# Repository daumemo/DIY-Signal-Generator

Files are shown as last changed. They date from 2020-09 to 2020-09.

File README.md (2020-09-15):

# DIY-Signal-Generator

diy-generator-image

A device, used for generating electrical signals. More infromation: https://daumemo.com/finished-diy-portable-wi-fi-function-generator-part-17

Repository includes all files: firmware code, schematics, PCB files.
STL files for the enclosure can be found here: https://www.thingiverse.com/thing:4596954

Device's specification:
- 3.5 inch IPS LCD with capacitive touch panel
- 2200 mAh Li-Po battery
- ESP-32 MCU
- AD9833 for sine and triangle waveform generation (up to 25 MHz)
- Square wave and PWM generated by the MCU (up to 5 MHz)
- The device can be controlled through LCD or WEB interface
- For WEB control, the device can connect to a Wi-Fi or it can create its own Wi-Fi Access Point
- Output signal’s offset range: -8V … +8V
- Output signal’s amplitude range: 0 … 9V (sine, triangle), 0 … 5.5V (square). PWM output: 3V.
- Battery charging time: <2 hours
- Working time (Wi-Fi on, output relay ON, maximum LCD brightness): around 6 hours
- USB Type C port for charging, 2 SMA ports for signal output, 1 ON/OFF switch, LED charging indicator

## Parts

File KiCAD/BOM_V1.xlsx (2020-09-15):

Date: | 2020-05-26 00:24 | additional modification 2020-09-15
Tool: | Eeschema (5.1.4)-1
NOTE: capacitor voltages specified below are recommended values - it is OK to use capacitors with greater rated voltage. To use lower value - you will need to inspect schematic and decide if lower voltage is acceptable
Component Count: | 141
Ref | Value | Footprint | Description | Remarks, links etc.
C1 | 1u 10V | SMD 0603 | Unpolarized capacitor
C2 | 1u 10V | SMD 0603 | Unpolarized capacitor
C3 | 470n 16V | SMD 0603 | Unpolarized capacitor
C4 | 470n 16V | SMD 0603 | Unpolarized capacitor
C5 | 10uF 6V | SMD 0603 | Unpolarized capacitor
C6 | 10n 50V | SMD 0603 | Unpolarized capacitor
C7 | 22u 6V | SMD 0603 | Unpolarized capacitor
C8 | 100n 50V | SMD 0603 | Unpolarized capacitor
C9 | 470n 16V | SMD 0603 | Unpolarized capacitor
C10 | 2u2 10V | SMD 0603 | Unpolarized capacitor
C11 | 470n 16V | SMD 0603 | Unpolarized capacitor
C12 | 2u2 10V | SMD 0603 | Unpolarized capacitor
C13 | 100n 50V | SMD 0603 | Unpolarized capacitor
C14 | not soldered in | SMD 0603 | Unpolarized capacitor (not soldered in)
C15 | 100n 50V | SMD 0603 | Unpolarized capacitor
C16 | 1u 16V | SMD 0603 | Unpolarized capacitor
C17 | 100n 50V | SMD 0603 | Unpolarized capacitor
C18 | 1u 16V | SMD 0603 | Unpolarized capacitor
C19 | 100u 6V | SMD Case-B (EIA-3528) | Polarized tantalum capacitor
C20 | 100n 50V | SMD 0603 | Unpolarized capacitor
C21 | 4u7 6V | SMD 0603 | Unpolarized capacitor
C22 | 1u 10V | SMD 0603 | Unpolarized capacitor
C23 | 10n 50V | SMD 0603 | Unpolarized capacitor
C24 | 220n 16V | SMD 0603 | Unpolarized capacitor
C25 | 4n7 50V | SMD 0603 | Unpolarized capacitor
C26 | 47n 16V | SMD 0603 | Unpolarized capacitor
C27 | 4u7 6V | SMD 0603 | Unpolarized capacitor
C28 | 4u7 16V | SMD 0805 | Unpolarized capacitor
C29 | 10u 6V | SMD 0603 | Unpolarized capacitor
C30 | 10u 6V | SMD 0603 | Unpolarized capacitor
C31 | 4u7 16V | SMD 0805 | Unpolarized capacitor
C32 | 22u 16V | SMD Case-B (EIA-3528) | Polarized tantalum capacitor
C33 | 22u 16V | SMD Case-B (EIA-3528) | Polarized tantalum capacitor
C34 | 10u 6V | SMD 0603 | Unpolarized capacitor
C35 | 10u 10V | SMD 0603 | Unpolarized capacitor
C36 | 220uf 6V | SMD Case-C (EIA-6032) | Polarized tantalum capacitor
C37 | 100n 50V | SMD 0603 | Unpolarized capacitor
C38 | 12p 50V | SMD 0603 | Unpolarized capacitor
C39 | 2u2 6V | SMD 0603 | Unpolarized capacitor
C40 | 10u 6V | SMD 0603 | Unpolarized capacitor
C41 | 100u 6V | SMD Case-B (EIA-3528) | Polarized tantalum capacitor
C42 | 12p 50V | SMD 0603 | Unpolarized capacitor
C43 | 470n 16V | SMD 0603 | Unpolarized capacitor
C44 | 10u 6V | SMD 0603 | Unpolarized capacitor
C45 | 10u 10V | SMD 0603 | Unpolarized capacitor
C46 | 100u 6V | SMD 1206 | Unpolarized capacitor
C47 | 10n 50V | SMD 0603 | Unpolarized capacitor
C48 | 10u 6V | SMD 0603 | Unpolarized capacitor
C49 | 1u 10V | SMD 0603 | Unpolarized capacitor
C50 | 10u 6V | SMD 0603 | Unpolarized capacitor
C51 | 5n6 25V | SMD 0603 | Unpolarized capacitor
C52 | 5n6 25V | SMD 0603 | Unpolarized capacitor
D1 | LED, amber | SMD LED 0603 | Light emitting diode
D2 | PMEG3010EH | SMD SOD-123 | Schottky diode | Could be used similar diode
D3 | PMEG3010EH | SMD SOD-123 | Schottky diode | Could be used similar diode
D4 | PMEG3010EH | SMD SOD-123 | Diode | Can be a regular diode in SOD-123 case
J1 | Wave_Out | SMA-J-P-X-ST-EM1_EdgeMount | coaxial connector SMA | https://www.aliexpress.com/item/32948380887.html?spm=a2g0s.9042311.0.0.27424c4doeMCJ3
J2 | PWM_Out | SMA-J-P-X-ST-EM1_EdgeMount | coaxial connector SMA | https://www.aliexpress.com/item/32948380887.html?spm=a2g0s.9042311.0.0.27424c4doeMCJ3
J3 | USB_C_Receptacle_USB2.0 | Type-C:HRO-TYPE-C-31-M-12-HandSoldering | USB 2.0-only Type-C Receptacle connector | https://www.aliexpress.com/item/32962977859.html?spm=a2g0s.9042311.0.0.27424c4depynTn
J4 | TS |  | PCB connector
J5 | GND |  | PCB connector
J6 | BAT |  | PCB connector | Lipo/Liion Battery +
J7 | GND |  | PCB connector | Lipo/Liion Battery -
J8 | UART |  | PCB connector
J9 | I2C (not soldered in) | FinalPCB:User_FPC_4pin_05pitch_bot_cont | FPC 4pin connector | Not soldered in (not used)
J10 | 40pin_LCD | FinalPCB:User_FPC_40pin_05pitch_BottomContact | FPC 40pin horizontal bottom contact connector
J11 | LCD_Touch | FinalPCB:User_FPC_6pin_05pitch_top_cont | FPC 6pin horizontal top contact connector
K1 | G6K-2F-Y | Relay_DPDT_Omron_G6K-2F-Y | Miniature 2-pole relay, Single-side Stable
L1 | 4u7 | SMD:4x4mm NRS4012T4R7MDGJ | Inductor | https://eu.mouser.com/ProductDetail/Taiyo-Yuden/NRS4012T4R7MDGJ?qs=PzICbMaShUcMjc7xtptbAQ%3D%3D
L2 | 4u7 | SMD:4x4mm NRS4012T4R7MDGJ | Inductor | https://eu.mouser.com/ProductDetail/Taiyo-Yuden/NRS4012T4R7MDGJ?qs=PzICbMaShUcMjc7xtptbAQ%3D%3D
L3 | 2u2 | SMD:4x4mm NRS4012T2R2MDGJ | Inductor | https://eu.mouser.com/ProductDetail/Taiyo-Yuden/NRS4012T2R2MDGJ
L4 | 4u7 | SMD:4x4mm NRS4012T4R7MDGJ | Inductor | https://eu.mouser.com/ProductDetail/Taiyo-Yuden/NRS4012T4R7MDGJ?qs=PzICbMaShUcMjc7xtptbAQ%3D%3D
L5 | 4u7 | SMD:4x4mm NRS4012T4R7MDGJ | Inductor | https://eu.mouser.com/ProductDetail/Taiyo-Yuden/NRS4012T4R7MDGJ?qs=PzICbMaShUcMjc7xtptbAQ%3D%3D
Q1 | BC847C | SMD SOT-23 | 0.1A Ic, 45V Vce, NPN Transistor, SOT-23
Q2 | NTR4003NT1G | SMD SOT-23 | N-MOSFET transistor, gate/source/drain
Q3 | NTR4003NT1G | SMD SOT-23 | N-MOSFET transistor, gate/source/drain
R1 | 1k3 | SMD 0603 | Resistor
R2 | 3k9 | SMD 0603 | Resistor
R3 | 22k | SMD 0603 | Resistor
R4 | 22k | SMD 0603 | Resistor
R5 | 2k | SMD 0603 | Resistor
R6 | 2k | SMD 0603 | Resistor
R7 | 9k1 | SMD 0603 | Resistor
R8 | 1k | SMD 0603 | Resistor
R9 | 1k3 | SMD 0603 | Resistor
R10 | 3k9 | SMD 0603 | Resistor
R11 | 200 | SMD 0603 | Resistor
R12 | 1k | SMD 0603 | Resistor
R13 | 22k | SMD 0603 | Resistor
R14 | 22k | SMD 0603 | Resistor
R15 | 1k | SMD 0603 | Resistor
R16 | 0 | SMD 0603 | Resistor
R17 | not soldered in | SMD 0603 | Resistor
R18 | 240 | SMD 0603 | Resistor
R19 | 240 | SMD 0603 | Resistor
R20 | 240 | SMD 0603 | Resistor
R21 | 910 | SMD 0603 | Resistor
R22 | 18k | SMD 0603 | Resistor
R23 | 0 | SMD 0805 | Resistor
R24 | 100 | SMD 0603 | Resistor
R25 | 5k1 | SMD 0603 | Resistor
R26 | 5k1 | SMD 0603 | Resistor
R27 | 10k | SMD 0603 | Resistor
R28 | 10k | SMD 0603 | Resistor
R29 | 0 | SMD 0603 | Resistor
R30 | 0 or not soldered | SMD 0603 | Resistor | if soldered in - power saving mode
R31 | 0 | SMD 0603 | Resistor
R32 | 0 or not soldered | SMD 0603 | Resistor | if soldered in - power saving mode
R33 | 240 | SMD 0603 | Resistor
R34 | 10k | SMD 0603 | Resistor
R35 | 1k8 | SMD 0603 | Resistor
R36 | 100k | SMD 0603 | Resistor
R37 | 1M | SMD 0603 | Resistor
R38 | 4k3 | SMD 0603 | Resistor
R39 | 20k | SMD 0603 | Resistor
R40 | 1M | SMD 0603 | Resistor
R41 | 110k | SMD 0603 | Resistor
R42 | 15k | SMD 0603 | Resistor
R43 | 20k | SMD 0603 | Resistor
R44 | 160k | SMD 0603 | Resistor
R45 | 51k | SMD 0603 | Resistor
R46 | 100 | SMD 0603 | Resistor
R47 | 130k | SMD 0603 | Resistor
R48 | 56k | SMD 0603 | Resistor
R49 | 12k | SMD 0603 | Resistor
R50 | 10k | SMD 0603 | Resistor
R51 | 3k3 | SMD 0603 | Resistor
R52 | 3k3 | SMD 0603 | Resistor
R53 | 1M | SMD 0603 | Resistor
R54 | 0 | SMD 0603 | Resistor
R55 | 0 | SMD 0603 | Resistor
R56 | 1R | SMD 1206 | Resistor
R57 | 470 | SMD 0603 | Resistor
SW1 |  | FinalPCB:Switch | Single Pole Single Throw (SPST) switch | https://www.aliexpress.com/item/32852841524.html?scm_id=1007.14977.165002.0&scm-url=1007.14977.165002.0
U1 | OPA2196 | SOIC:SOIC-8_3.9x4.9mm_Pitch1.27mm | Dual SoundPlus High Performance Audio Operational Amplifiers SOIC-8
U2 | VCA822 | SSOP:MSOP-10_3x3mm_Pitch0.5mm | Variable gain operational amplifier
U3 | LM7171 | SOIC:SOIC-8_3.9x4.9mm_Pitch1.27mm | High bandwidth operational amplifier
U4 | TPS65131 | QFN-24-1EP_4x4mm_Pitch0.5mm | DC-DC converter
U5 | BQ24295 | QFN-24-1EP_4x4mm_Pitch0.5mm | Battery charging IC
U6 | LDL1117-3.0 | SOT-223-3_TabPin2 | 1A Fixed LDO Linear Regulator, 3.0V SOT-223
U7 | LV52117QA | LV52117:LV52117QA | DC-DC converter
U8 | ESP32-WROOM-32 | ESP32-WROOM-32 | RF Module, ESP32-D0WDQ6 SoC, Wi-Fi 802.11b/g/n, Bluetooth, BLE, 32-bit, 2.7-3.6V, onboard antenna, SMD | https://www.aliexpress.com/item/32799985552.html?spm=a2g0s.9042311.0.0.27424c4doeMCJ3
U9 | AD9833_module | AD9833_module |  | https://www.aliexpress.com/item/32998169276.html
EXTERNAL COMPONENTS:
LCD 3.5 inch |  | Connected to J11 and J10 |  | https://www.aliexpress.com/item/32940608152.html
Thermistor | NTCLG100E2103JB | Connected to J4 and J5 | Could be used similar | https://eu.mouser.com/ProductDetail/Vishay-BC-Components/NTCLG100E2103JB
Battery |  |  | Li-Po 2200mAh 405580 | https://www.aliexpress.com/item/32986724542.html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

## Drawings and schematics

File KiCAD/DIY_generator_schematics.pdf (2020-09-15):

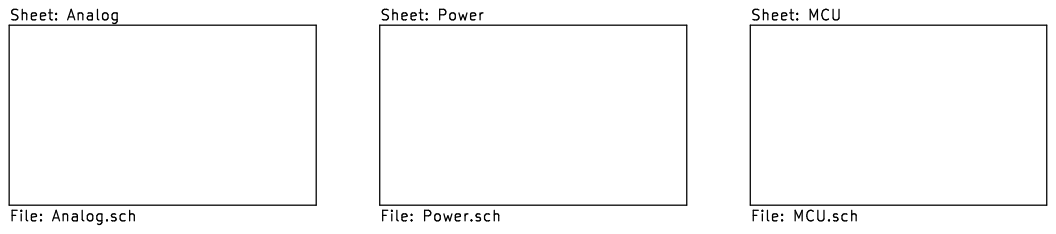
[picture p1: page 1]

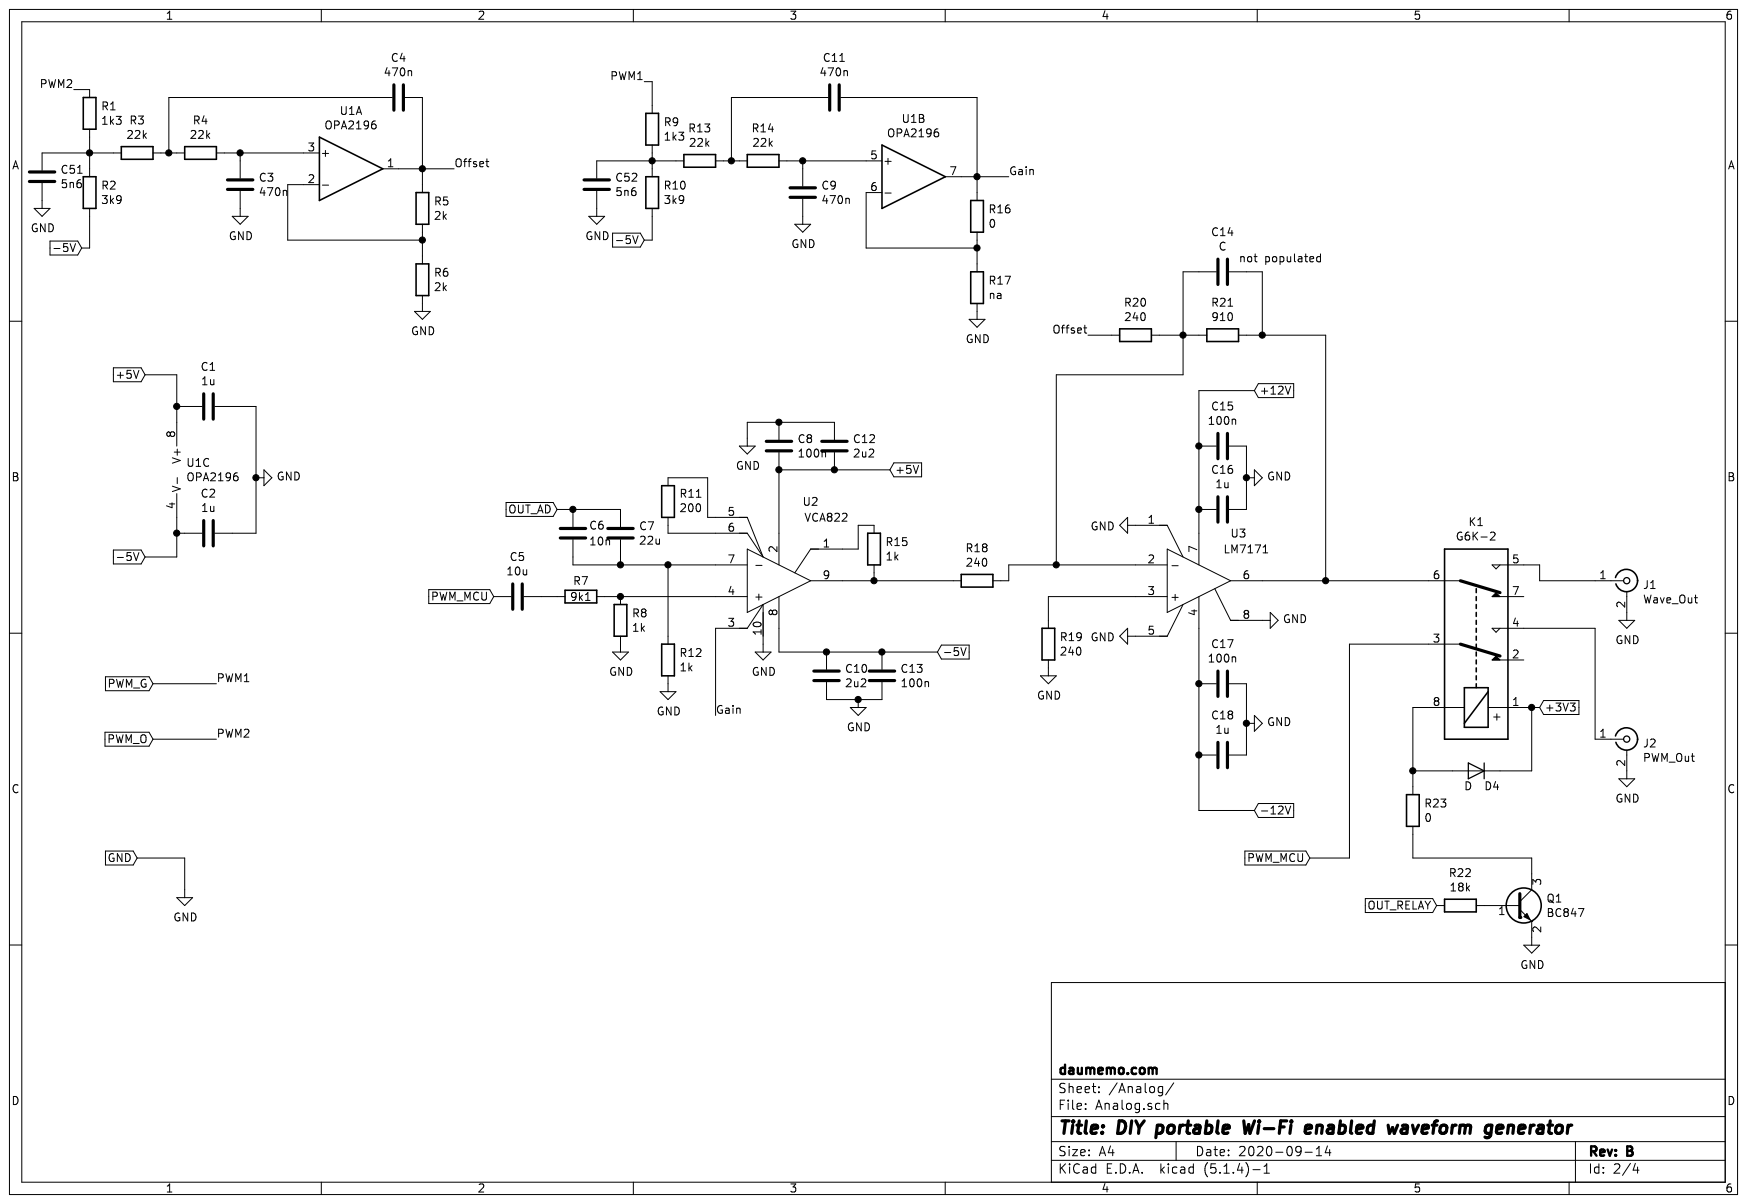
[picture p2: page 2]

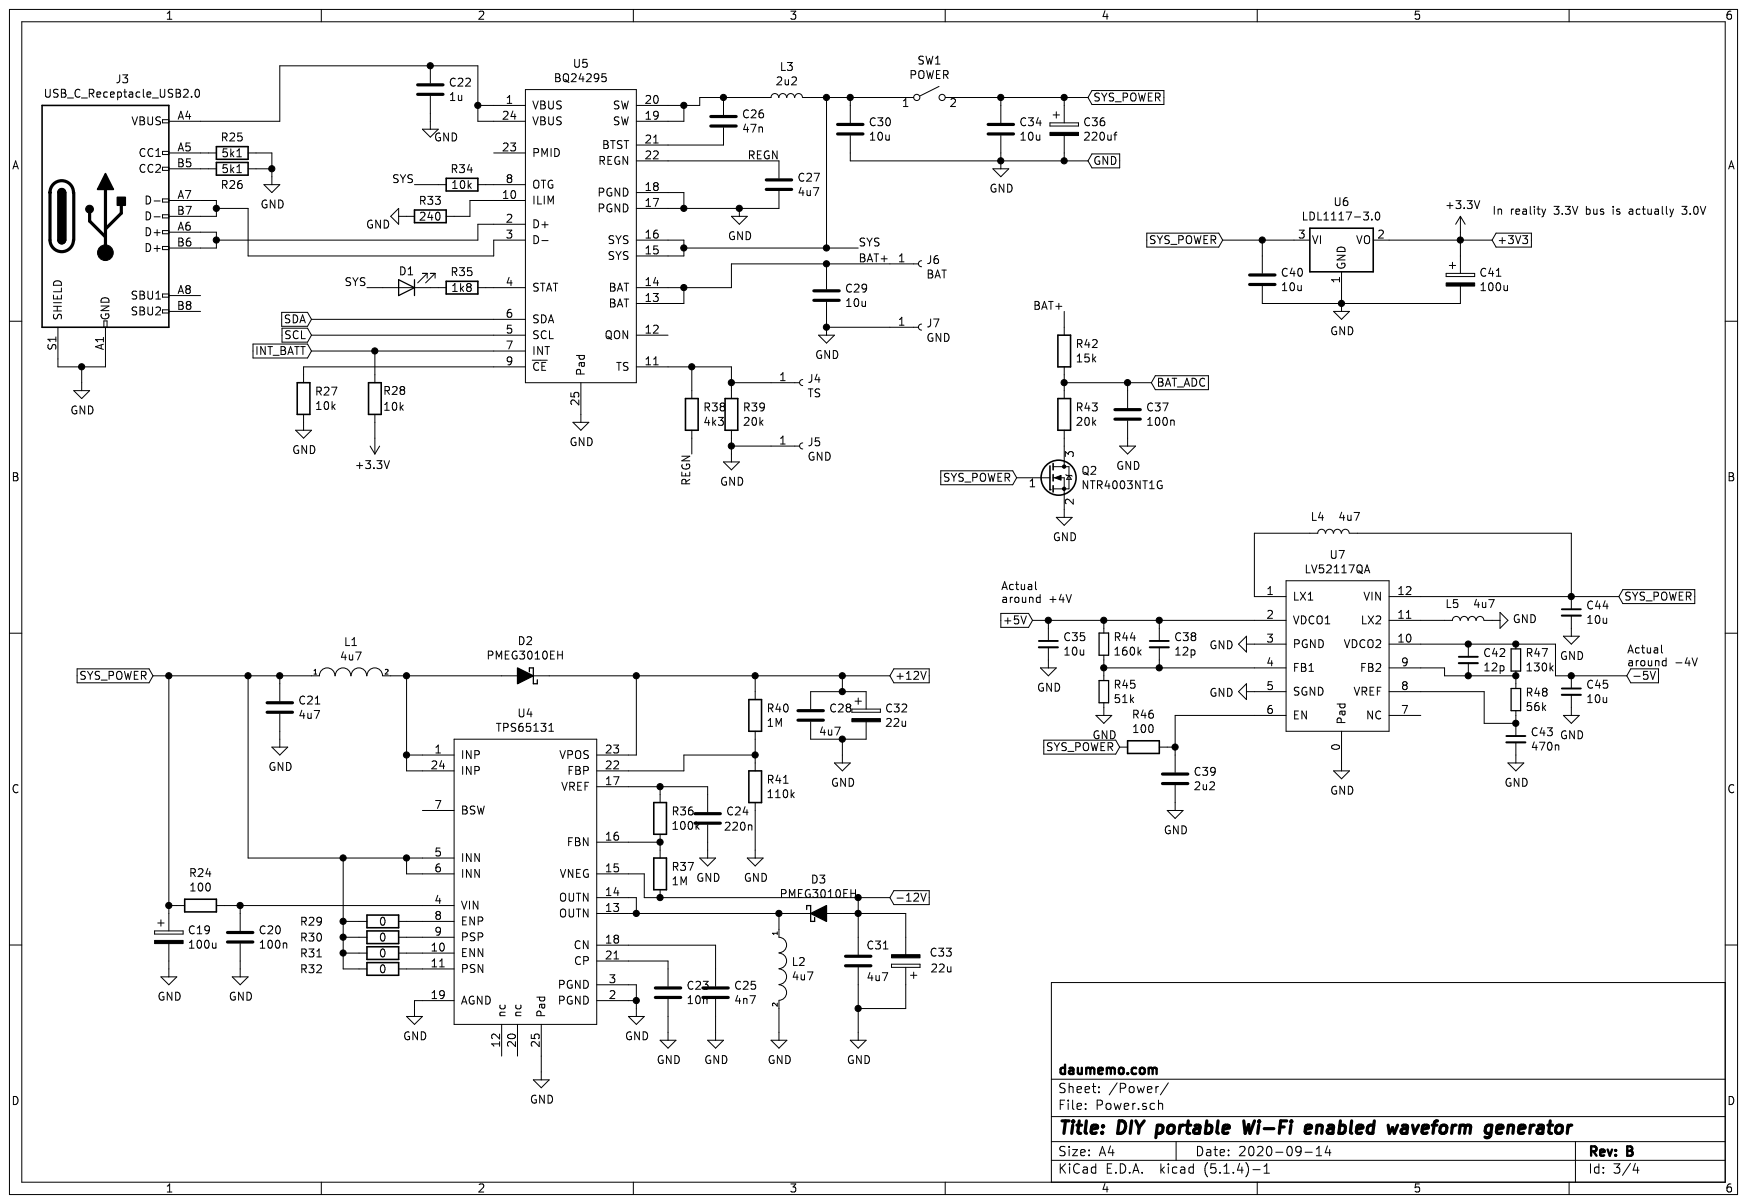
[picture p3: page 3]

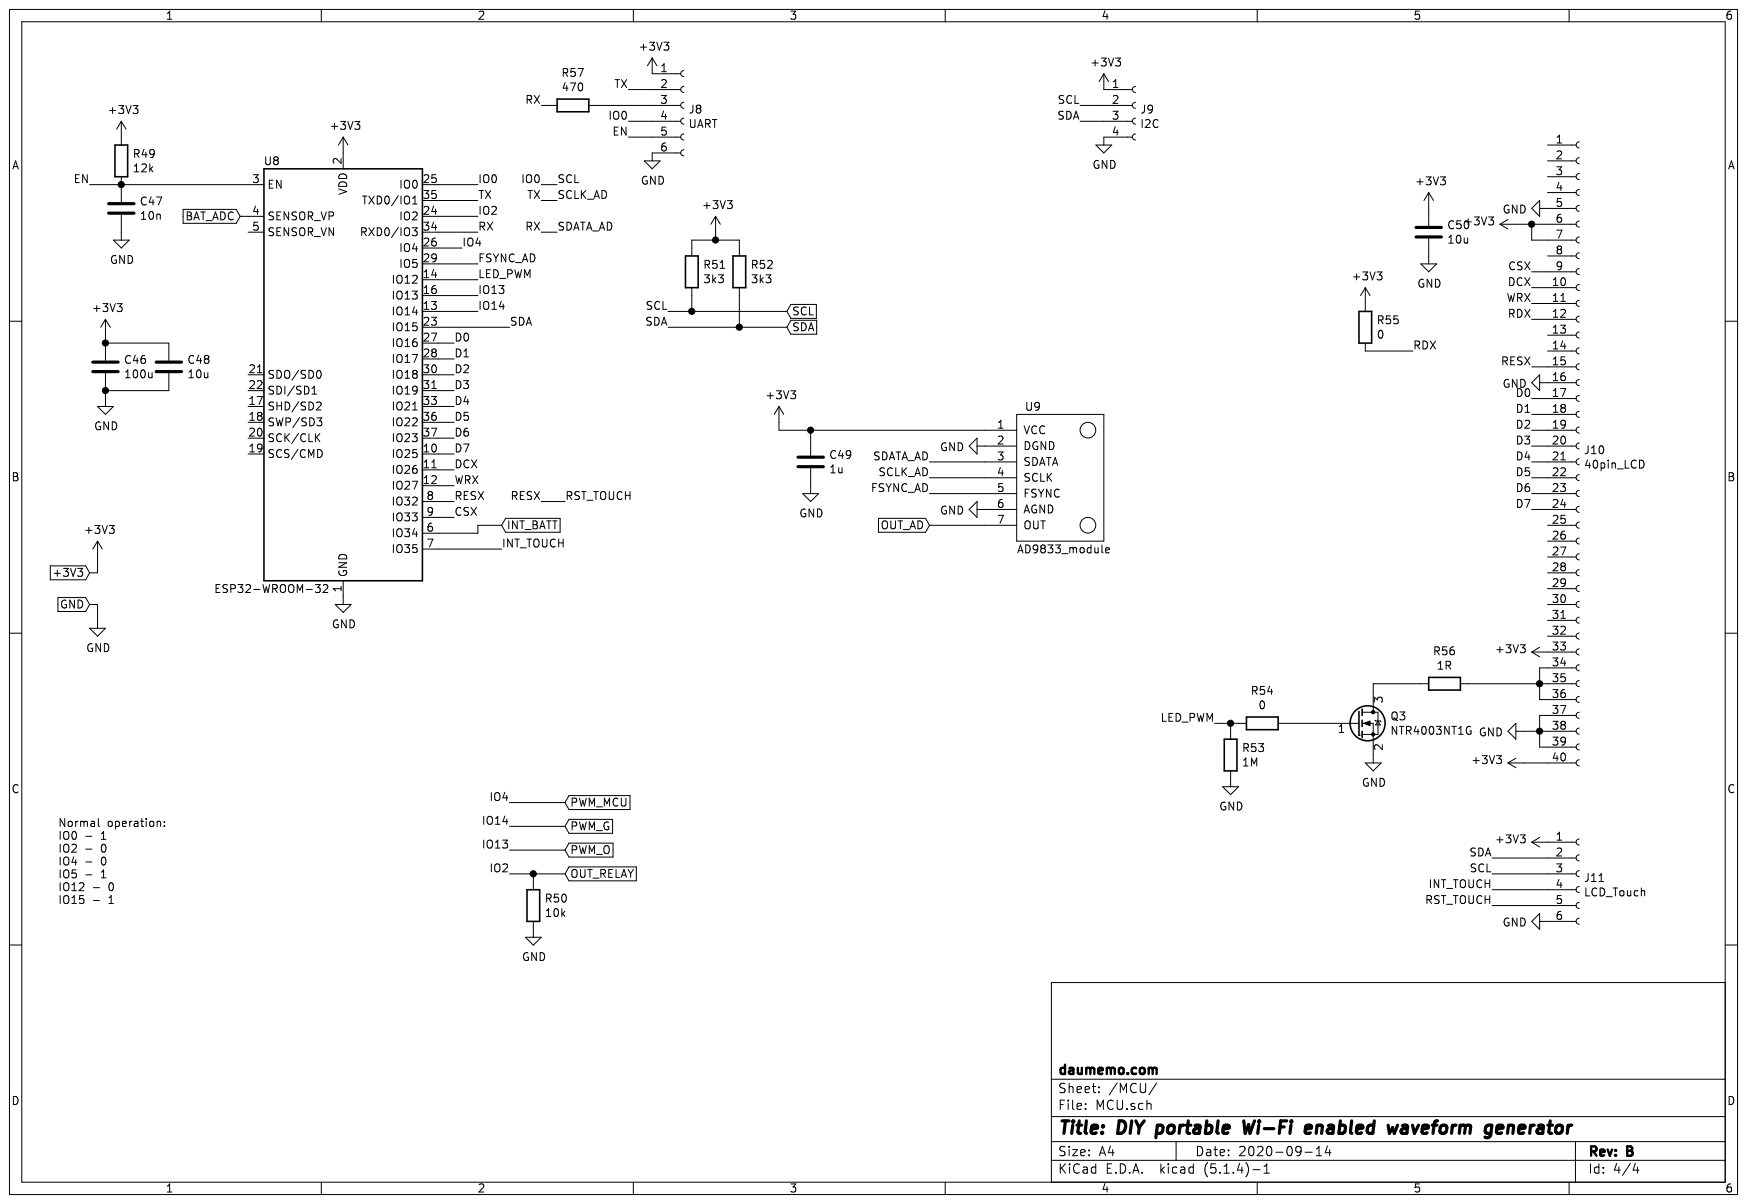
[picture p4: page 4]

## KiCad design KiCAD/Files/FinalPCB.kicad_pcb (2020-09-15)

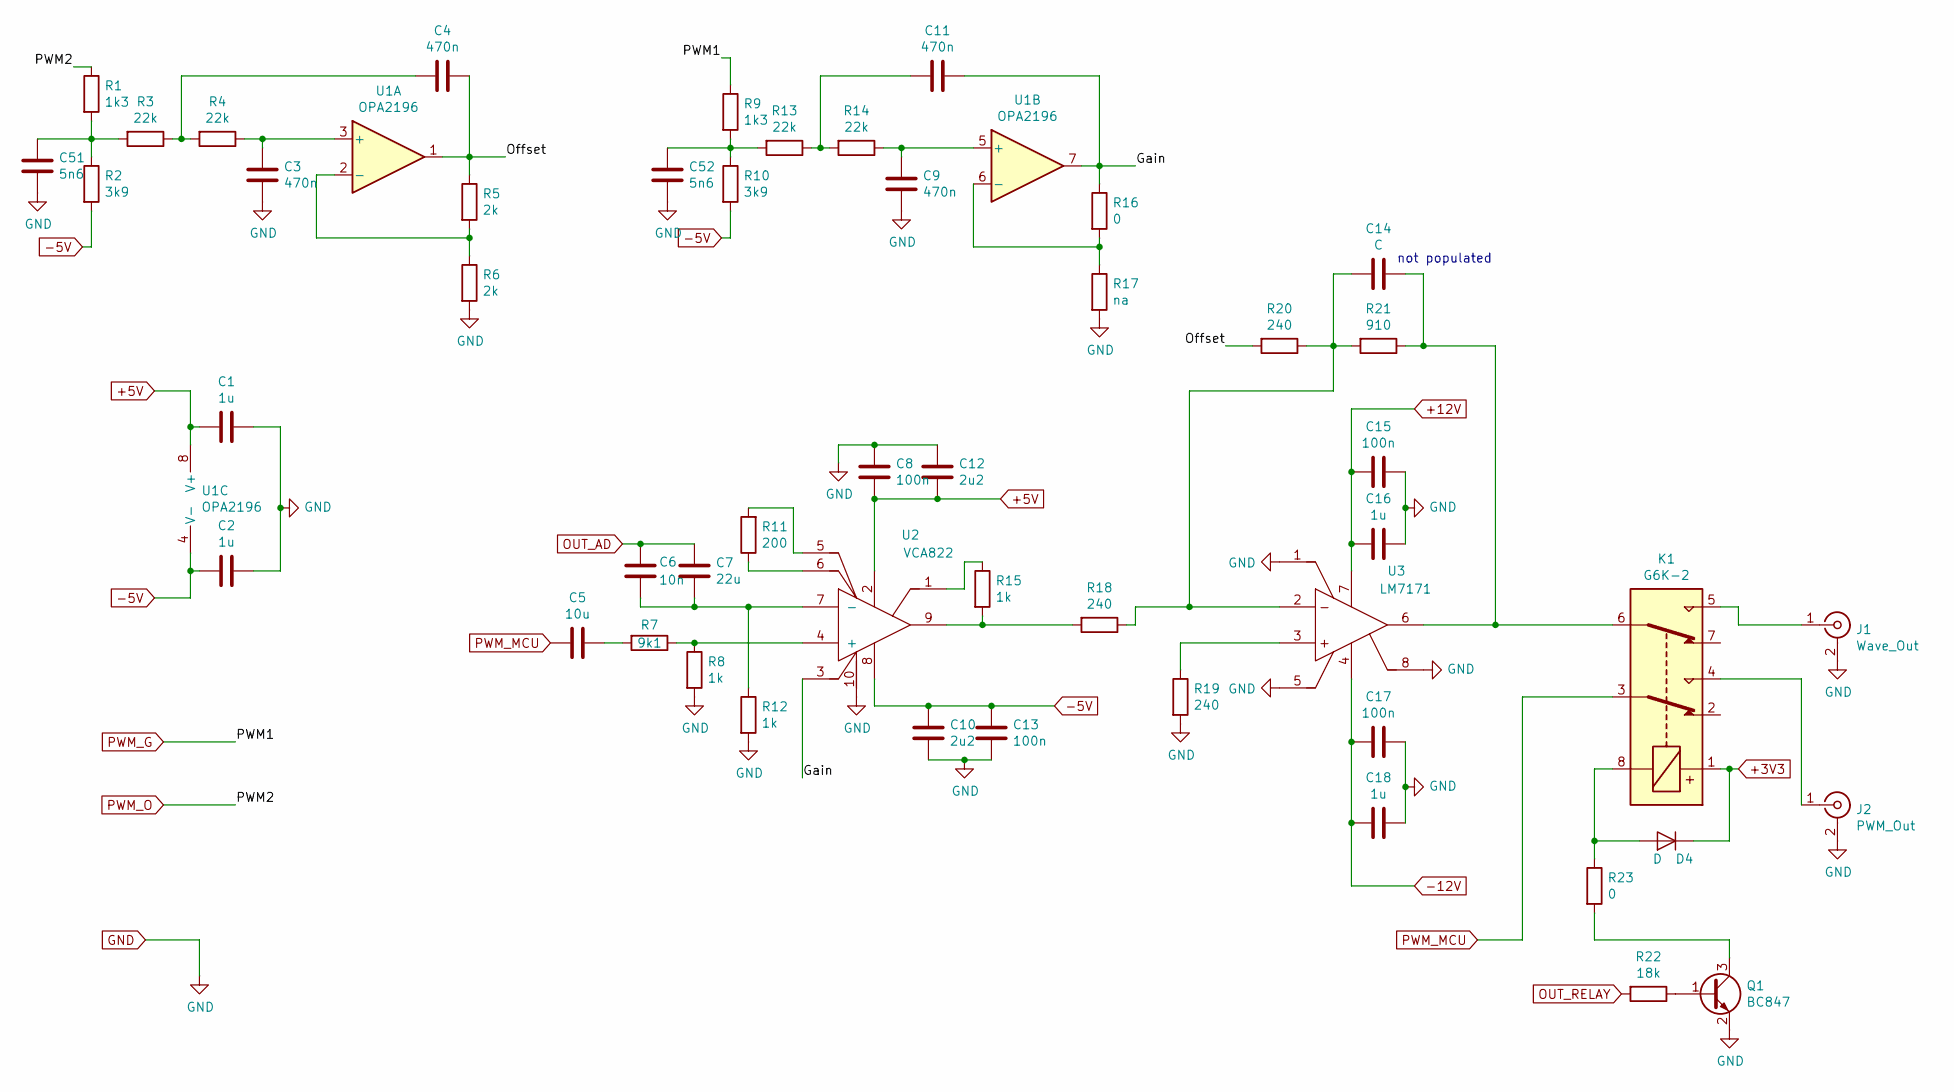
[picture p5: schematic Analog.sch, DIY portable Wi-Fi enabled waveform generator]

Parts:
C1, C2, C16, C18: 1u; C_0603
C3, C4, C9, C11: 470n; C_0603
C5: 10u; C_0603
C6: 10n; C_0603
C7: 22u; C_0603
C8, C13, C15, C17: 100n; C_0603
C10, C12: 2u2; C_0603
C14: C; C_0603
C51, C52: 5n6; C_0603
D4: D; D_SOD-123
J1: Wave_Out; SMA_Samtec_SMA-J-P-X-ST-EM1_EdgeMount
J2: PWM_Out; SMA_Samtec_SMA-J-P-X-ST-EM1_EdgeMount
K1: G6K-2; Relay_DPDT_Omron_G6K-2F-Y
Q1: BC847; SOT-23
R1, R9: 1k3; R_0603
R2, R10: 3k9; R_0603
R3, R4, R13, R14: 22k; R_0603
R5, R6: 2k; R_0603
R7: 9k1; R_0603
R8, R12, R15: 1k; R_0603
R11: 200; R_0603
R16: 0; R_0603
R17: na; R_0603
R18, R19, R20: 240; R_0603
R21: 910; R_0603
R22: 18k; R_0603
R23: 0; R_0805
U1: OPA2196; SOIC-8_3.9x4.9mm_Pitch1.27mm
U2: VCA822; MSOP-10_3x3mm_Pitch0.5mm
U3: LM7171; SOIC-8_3.9x4.9mm_Pitch1.27mm

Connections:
+3V3: D4.1 (K), K1.1; also elsewhere on the board
+5V: C1.2, C8.2, C12.2, U1.8 (V+), U2.2; also elsewhere on the board
+12V: C15.2, C16.2, U3.7; also elsewhere on the board
-5V: C2.2, C10.1, C13.1, R2.2, R10.2, U1.4 (V-), U2.8; also elsewhere on the board
-12V: C17.2, C18.2, U3.4; also elsewhere on the board
/Analog/Gain: C11.1, R16.1, U1.7, U2.3
/Analog/Offset: C4.1, R5.1, R20.2, U1.1
GND: C1.1, C2.1, C3.2, C8.1, C9.2, C10.2, C12.1, C13.2, C15.1, C16.1, C17.1, C18.1, C51.2, C52.2, J1.2 (Ext), J2.2 (Ext), Q1.2 (E), R6.2, R8.2, R12.2, R17.2, R19.2, U2.10, U3.1, U3.5, U3.8; also elsewhere on the board
unnamed: C3.1, R4.1, U1.3 (+)
unnamed: C4.2, R3.1, R4.2
unnamed: C5.1, R7.2
unnamed: C6.2, C7.2, R12.1, U2.7 (-)
unnamed: C9.1, R14.1, U1.5 (+)
unnamed: C11.2, R13.1, R14.2
unnamed: C14.1, K1.6, R21.1, U3.6
unnamed: C14.2, R18.1, R20.1, R21.2, U3.2
unnamed: C51.1, R1.2, R2.1, R3.2
unnamed: C52.1, R9.2, R10.1, R13.2
unnamed: D4.2 (A), K1.8, R23.1
unnamed: J1.1 (In), K1.5
unnamed: J2.1 (In), K1.4
unnamed: Q1.1 (B), R22.1
unnamed: Q1.3 (C), R23.2
unnamed: R5.2, R6.1, U1.2 (-)
unnamed: R7.1, R8.1, U2.4 (+)
unnamed: R11.1, U2.6
unnamed: R11.2, U2.5
unnamed: R15.1, U2.1
unnamed: R15.2, R18.2, U2.9
unnamed: R16.2, R17.1, U1.6 (-)
unnamed: R19.1, U3.3
OUT_AD: C6.1, C7.1; also elsewhere on the board
OUT_RELAY: R22.2; also elsewhere on the board
PWM_G: R9.1; also elsewhere on the board
PWM_MCU: C5.2, K1.3; also elsewhere on the board
PWM_O: R1.1; also elsewhere on the board

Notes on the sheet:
not populated

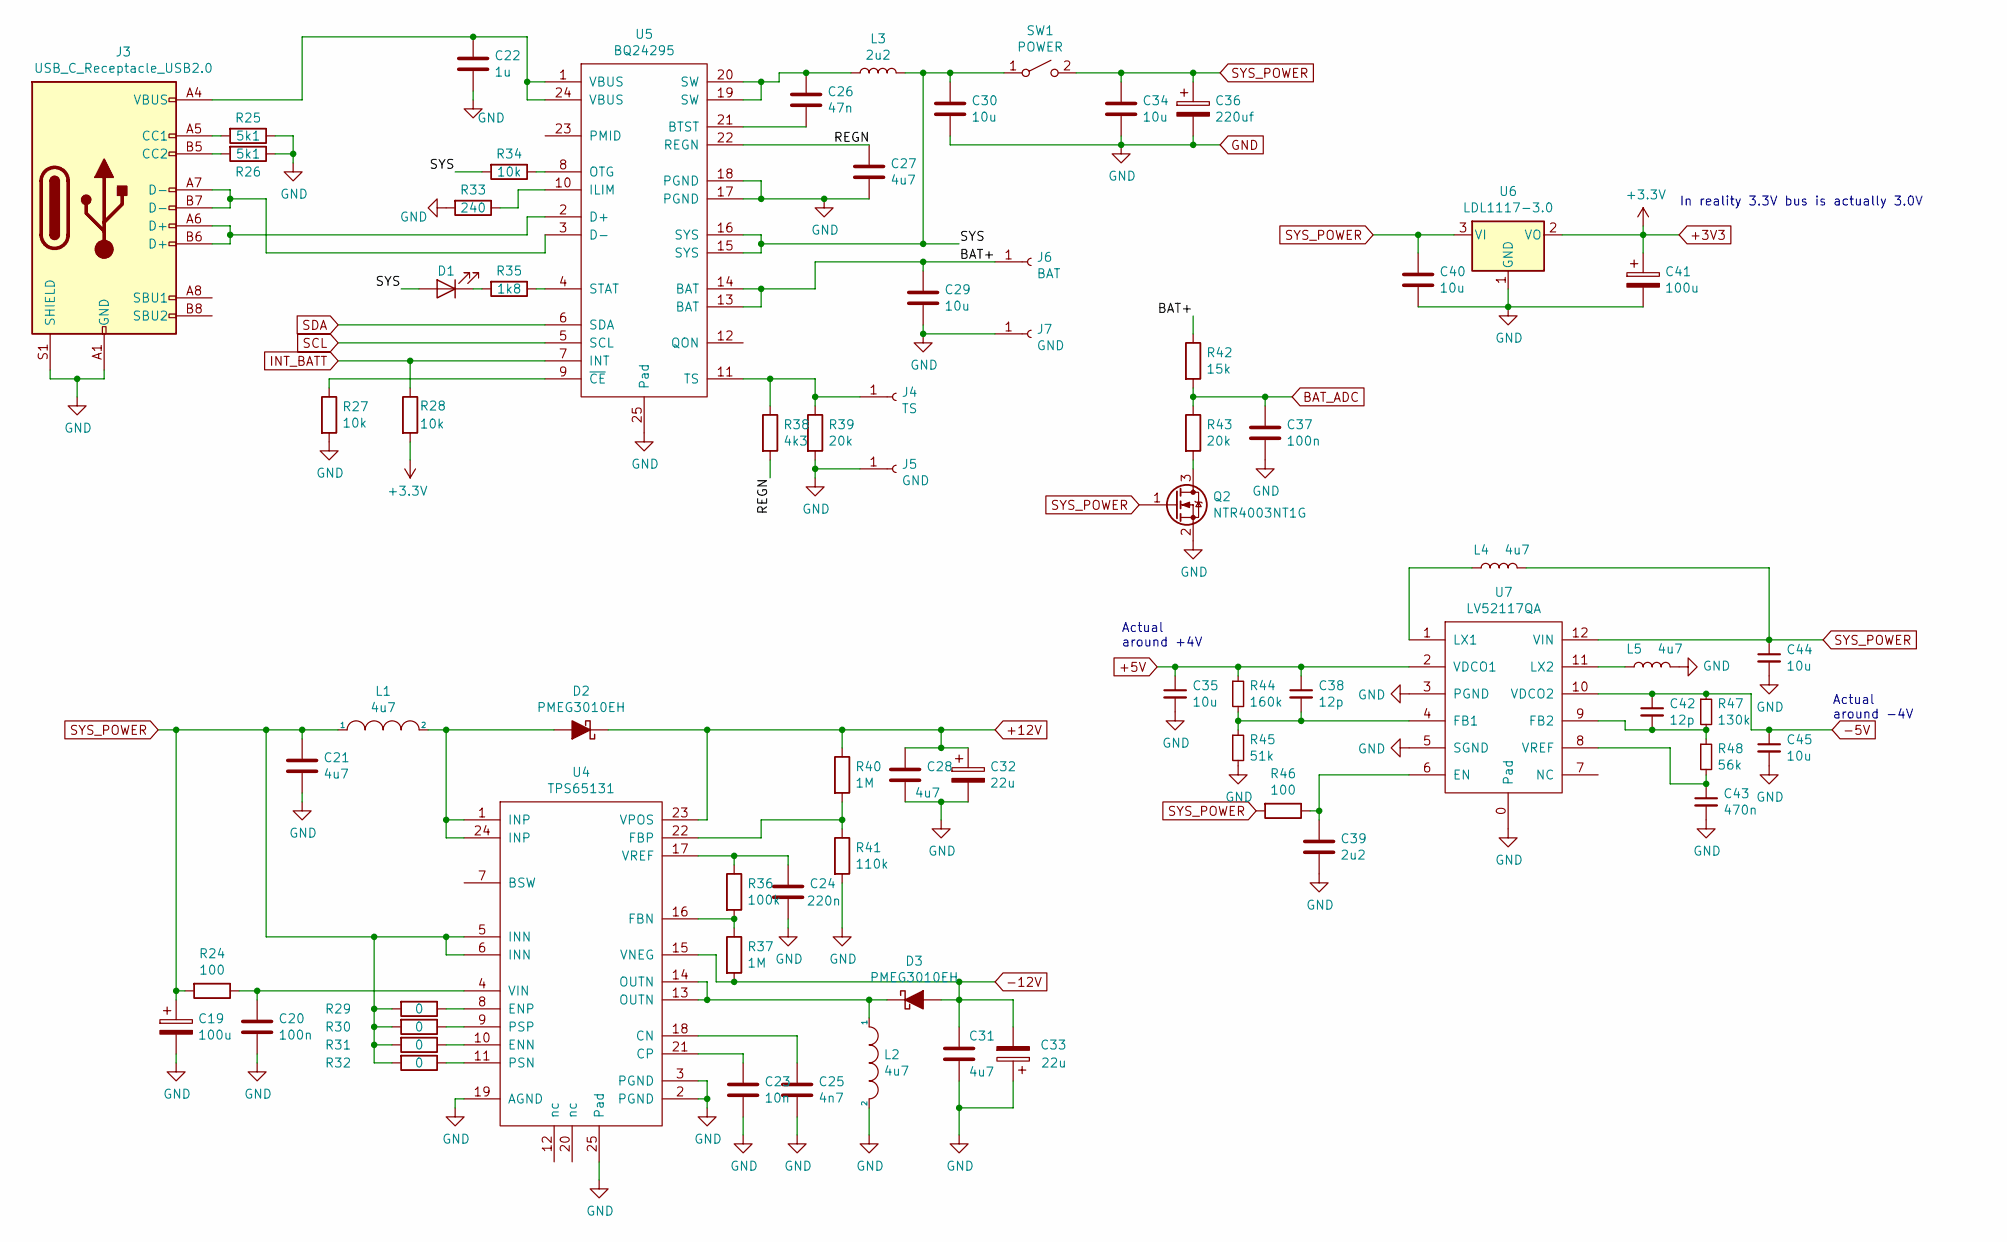
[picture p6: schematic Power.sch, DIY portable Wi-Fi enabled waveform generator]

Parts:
C19, C41: 100u; CP_Tantalum_Case-B_EIA-3528-21_Reflow
C20, C37: 100n; C_0603
C21, C27: 4u7; C_0603
C22: 1u; C_0603
C23: 10n; C_0603
C24: 220n; C_0603
C25: 4n7; C_0603
C26: 47n; C_0603
C28, C31: 4u7; C_0805
C29, C30, C34, C35, C40, C44, C45: 10u; C_0603
C32, C33: 22u; CP_Tantalum_Case-B_EIA-3528-21_Reflow
C36: 220uf; CP_Tantalum_Case-C_EIA-6032-28_Reflow
C38, C42: 12p; C_0603
C39: 2u2; C_0603
C43: 470n; C_0603
D1: LED; LED_0603
D2, D3: PMEG3010EH; D_SOD-123
J3: USB_C_Receptacle_USB2.0; HRO-TYPE-C-31-M-12-HandSoldering
J4: TS; Measurement_Point_Square-SMD-Pad_Big
J5, J7: GND; Measurement_Point_Square-SMD-Pad_Big
J6: BAT; Measurement_Point_Square-SMD-Pad_Big
L1, L2, L4, L5: 4u7; L_Taiyo-Yuden_NR-40xx_HandSoldering
L3: 2u2; L_Taiyo-Yuden_NR-40xx_HandSoldering
Q2: NTR4003NT1G; SOT-23
R24, R46: 100; R_0603
R25, R26: 5k1; R_0603
R27, R28, R34: 10k; R_0603
R29, R30, R31, R32: 0; R_0603
R33: 240; R_0603
R35: 1k8; R_0603
R36: 100k; R_0603
R37, R40: 1M; R_0603
R38: 4k3; R_0603
R39, R43: 20k; R_0603
R41: 110k; R_0603
R42: 15k; R_0603
R44: 160k; R_0603
R45: 51k; R_0603
R47: 130k; R_0603
R48: 56k; R_0603
SW1: POWER; Switch
U4: TPS65131; QFN-24-1EP_4x4mm_Pitch0.5mm
U5: BQ24295; QFN-24-1EP_4x4mm_Pitch0.5mm
U6: LDL1117-3.0; SOT-223-3_TabPin2
U7: LV52117QA

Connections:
+3V3: C41.1, R28.2, U6.2 (VO); also elsewhere on the board
+5V: C35.1, C38.1, R44.1, U7.2 (VDCO1); also elsewhere on the board
+12V: C28.1, C32.1, D2.1 (K), R40.1, U4.23 (VPOS); also elsewhere on the board
-5V: C42.1, C45.1, R47.1, U7.10 (VDCO2); also elsewhere on the board
-12V: C31.1, C33.2, D3.2 (A), R37.2, U4.15 (VNEG); also elsewhere on the board
/Power/BAT+: C29.1, J6.1, R42.1, U5.13 (BAT), U5.14 (BAT)
/Power/REGN: C27.1, R38.2, U5.22 (REGN)
/Power/SYS: C30.1, D1.2 (A), L3.2, R34.2, SW1.1 (A), U5.15 (SYS), U5.16 (SYS)
BAT_ADC: C37.1, R42.2, R43.1; also elsewhere on the board
GND: C19.2, C20.2, C21.2, C22.2, C23.2, C24.2, C25.2, C27.2, C28.2, C29.2, C30.2, C31.2, C32.2, C33.1, C34.2, C35.2, C36.2, C37.2, C39.2, C40.2, C41.2, C43.2, C44.2, C45.2, J3.A1 (GND), J3.A12 (GND), J3.B1 (GND), J3.B12 (GND), J3.S1 (SHIELD), J5.1, J7.1, L2.2, L5.2, Q2.2 (S), R25.1, R26.1, R27.2, R33.2, R39.2, R41.2, R45.2, U4.2 (PGND), U4.3 (PGND), U4.19 (AGND), U4.25 (Pad), U5.17 (PGND), U5.18 (PGND), U5.25 (Pad), U6.1 (GND), U7.0 (Pad), U7.3 (PGND), U7.5 (SGND); also elsewhere on the board
INT_BATT: R28.1, U5.7 (INT); also elsewhere on the board
unnamed: C20.1, R24.1, U4.4 (VIN)
unnamed: C22.1, J3.A4 (VBUS), J3.A9 (VBUS), J3.B4 (VBUS), J3.B9 (VBUS), U5.1 (VBUS), U5.24 (VBUS)
unnamed: C23.1, U4.21 (CP)
unnamed: C24.1, R36.1, U4.17 (VREF)
unnamed: C25.1, U4.18 (CN)
unnamed: C26.1, L3.1, U5.19 (SW), U5.20 (SW)
unnamed: C26.2, U5.21 (BTST)
unnamed: C38.2, R44.2, R45.1, U7.4 (FB1)
unnamed: C39.1, R46.1, U7.6 (EN)
unnamed: C42.2, R47.2, R48.1, U7.9 (FB2)
unnamed: C43.1, R48.2, U7.8 (VREF)
unnamed: D1.1 (K), R35.2
unnamed: D2.2 (A), L1.2, U4.1 (INP), U4.24 (INP)
unnamed: D3.1 (K), L2.1, U4.13 (OUTN), U4.14 (OUTN)
unnamed: J3.A5 (CC1), R25.2
unnamed: J3.A6 (D+), J3.B6 (D+), U5.2 (D+)
unnamed: J3.A7 (D-), J3.B7 (D-), U5.3 (D-)
unnamed: J3.B5 (CC2), R26.2
unnamed: J4.1, R38.1, R39.1, U5.11 (TS)
unnamed: L4.1, U7.1 (LX1)
unnamed: L5.1, U7.11 (LX2)
unnamed: Q2.3 (D), R43.2
unnamed: R27.1, U5.9 (~CE)
unnamed: R29.1, U4.8 (ENP)
unnamed: R30.1, U4.9 (PSP)
unnamed: R31.1, U4.10 (ENN)
unnamed: R32.1, U4.11 (PSN)
unnamed: R33.1, U5.10 (ILIM)
unnamed: R34.1, U5.8 (OTG)
unnamed: R35.1, U5.4 (STAT)
unnamed: R36.2, R37.1, U4.16 (FBN)
unnamed: R40.2, R41.1, U4.22 (FBP)
SCL: U5.5 (SCL); also elsewhere on the board
SDA: U5.6 (SDA); also elsewhere on the board
SYS_POWER: C19.1, C21.1, C34.1, C36.1, C40.1, C44.1, L1.1, L4.2, Q2.1 (G), R24.2, R29.2, R30.2, R31.2, R32.2, R46.2, SW1.2 (B), U4.5 (INN), U4.6 (INN), U6.3 (VI), U7.12 (VIN)

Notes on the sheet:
In reality 3.3V bus is actually 3.0V
Actual around -4V
Actual around +4V

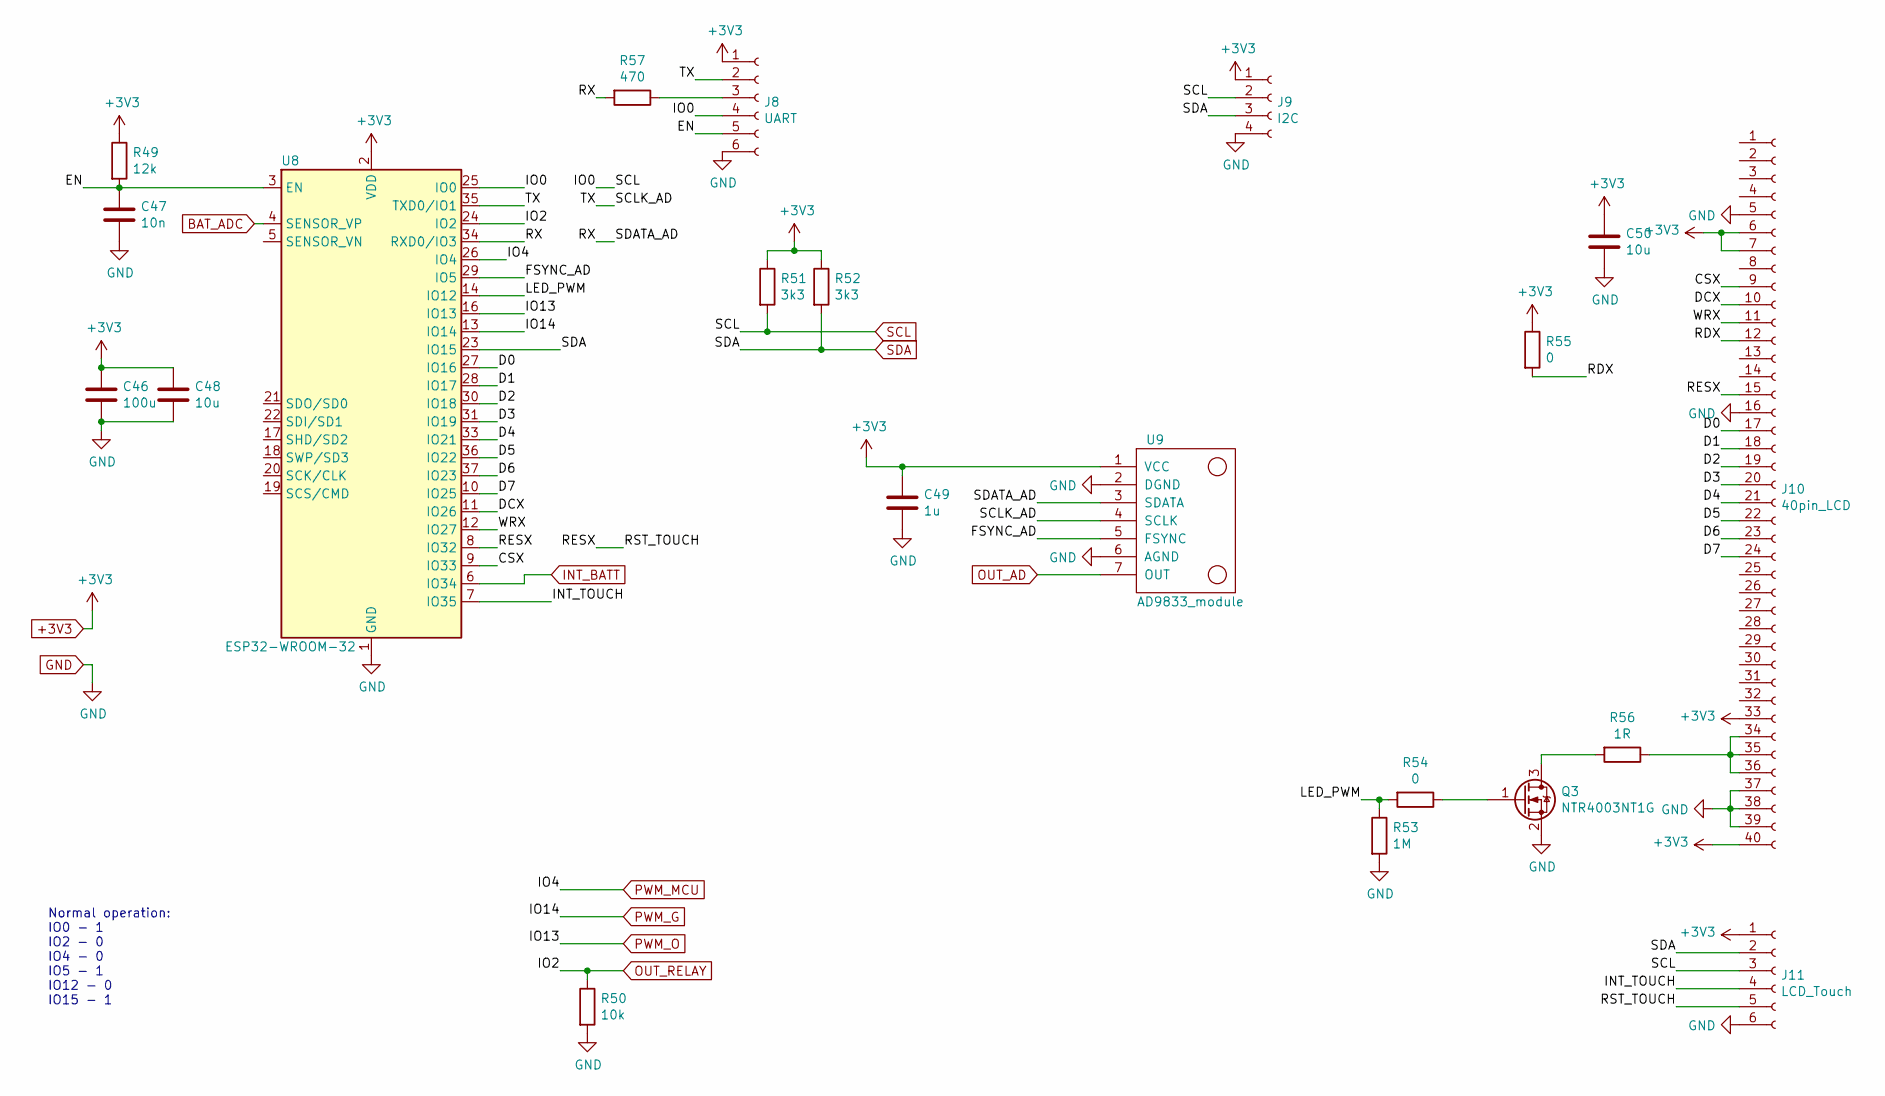
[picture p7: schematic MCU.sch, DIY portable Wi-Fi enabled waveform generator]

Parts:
C46: 100u; C_1206
C47: 10n; C_0603
C48, C50: 10u; C_0603
C49: 1u; C_0603
J8: UART; Pin_Header_Straight_1x06_Pitch2.54mm
J9: I2C; User_FPC_4pin_05pitch_bot_cont
J10: 40pin_LCD; User_FPC_40pin_05pitch_BottomContact
J11: LCD_Touch; User_FPC_6pin_05pitch_top_cont
Q3: NTR4003NT1G; SOT-23
R49: 12k; R_0603
R50: 10k; R_0603
R51, R52: 3k3; R_0603
R53: 1M; R_0603
R54, R55: 0; R_0603
R56: 1R; R_1206
R57: 470; R_0603
U8: ESP32-WROOM-32
U9: AD9833_module

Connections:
+3V3: C46.1, C48.1, C49.1, C50.1, J8.1, J9.1, J10.6, J10.7, J10.33, J10.40, J11.1, R49.1, R51.1, R52.1, R55.1, U8.2 (VDD), U9.1 (VCC); also elsewhere on the board
/MCU/CSX: J10.9, U8.9 (IO33)
/MCU/D0: J10.17, U8.27 (IO16)
/MCU/D1: J10.18, U8.28 (IO17)
/MCU/D2: J10.19, U8.30 (IO18)
/MCU/D3: J10.20, U8.31 (IO19)
/MCU/D4: J10.21, U8.33 (IO21)
/MCU/D5: J10.22, U8.36 (IO22)
/MCU/D6: J10.23, U8.37 (IO23)
/MCU/D7: J10.24, U8.10 (IO25)
/MCU/DCX: J10.10, U8.11 (IO26)
/MCU/EN: C47.1, J8.5, R49.2, U8.3 (EN)
/MCU/FSYNC_AD: U8.29 (IO5), U9.5 (FSYNC)
/MCU/INT_TOUCH: J11.4, U8.7 (IO35)
/MCU/LED_PWM: R53.1, R54.2, U8.14 (IO12)
/MCU/RDX: J10.12, R55.2
/MCU/RESX: J10.15, J11.5, U8.8 (IO32)
/MCU/RX: R57.2, U8.34 (RXD0/IO3), U9.3 (SDATA)
/MCU/SCLK_AD: J8.2, U8.35 (TXD0/IO1), U9.4 (SCLK)
/MCU/WRX: J10.11, U8.12 (IO27)
BAT_ADC: U8.4 (SENSOR_VP); also elsewhere on the board
GND: C46.2, C47.2, C48.2, C49.2, C50.2, J8.6, J9.4, J10.5, J10.16, J10.37, J10.38, J10.39, J11.6, Q3.2 (S), R50.2, R53.2, U8.1 (GND), U8.15 (GND), U8.38 (GND), U9.2 (DGND), U9.6 (AGND); also elsewhere on the board
INT_BATT: U8.6 (IO34); also elsewhere on the board
unnamed: J8.3, R57.1
unnamed: J10.34, J10.35, J10.36, R56.1
unnamed: Q3.1 (G), R54.1
unnamed: Q3.3 (D), R56.2
OUT_AD: U9.7 (OUT); also elsewhere on the board
OUT_RELAY: R50.1, U8.24 (IO2); also elsewhere on the board
PWM_G: U8.13 (IO14); also elsewhere on the board
PWM_MCU: U8.26 (IO4); also elsewhere on the board
PWM_O: U8.16 (IO13); also elsewhere on the board
SCL: J8.4, J9.2, J11.3, R51.2, U8.25 (IO0); also elsewhere on the board
SDA: J9.3, J11.2, R52.2, U8.23 (IO15); also elsewhere on the board

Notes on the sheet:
Normal operation: IO0 - 1 IO2 - 0 IO4 - 0 IO5 - 1 IO12 - 0 IO15 - 1

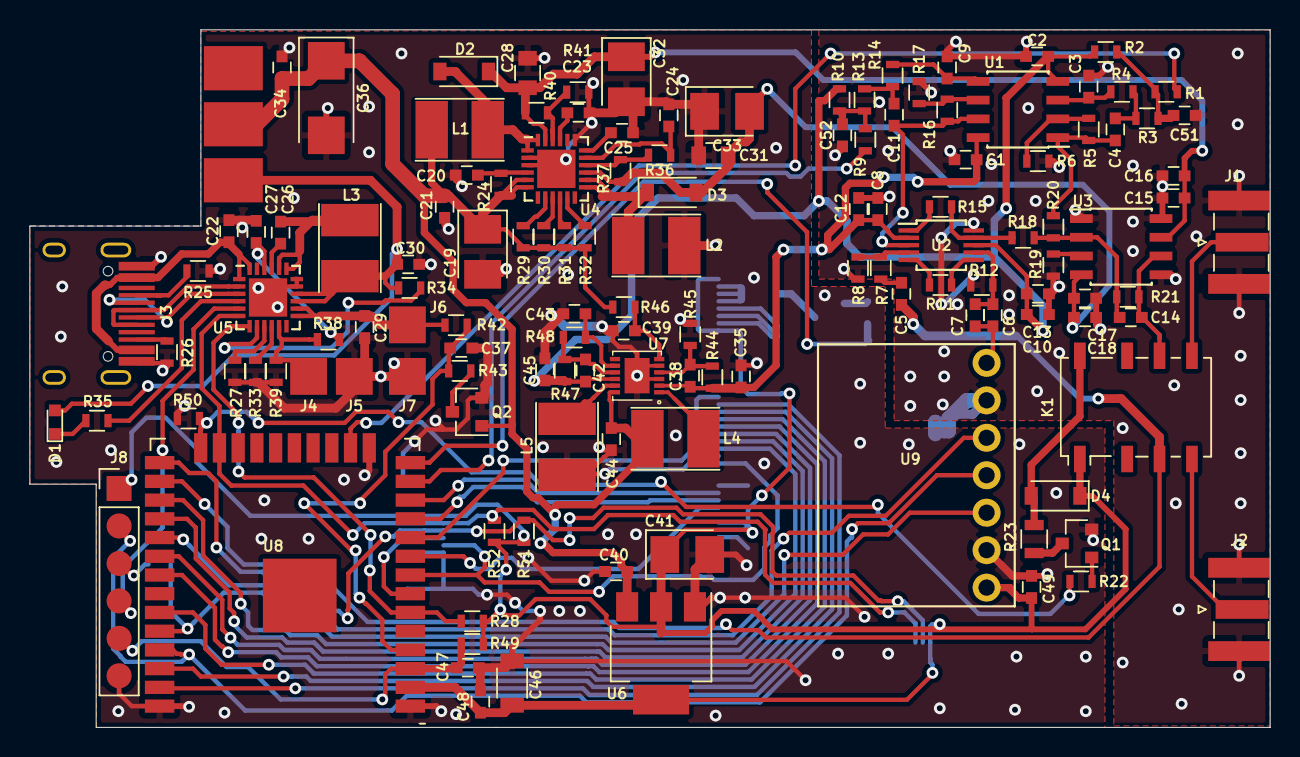
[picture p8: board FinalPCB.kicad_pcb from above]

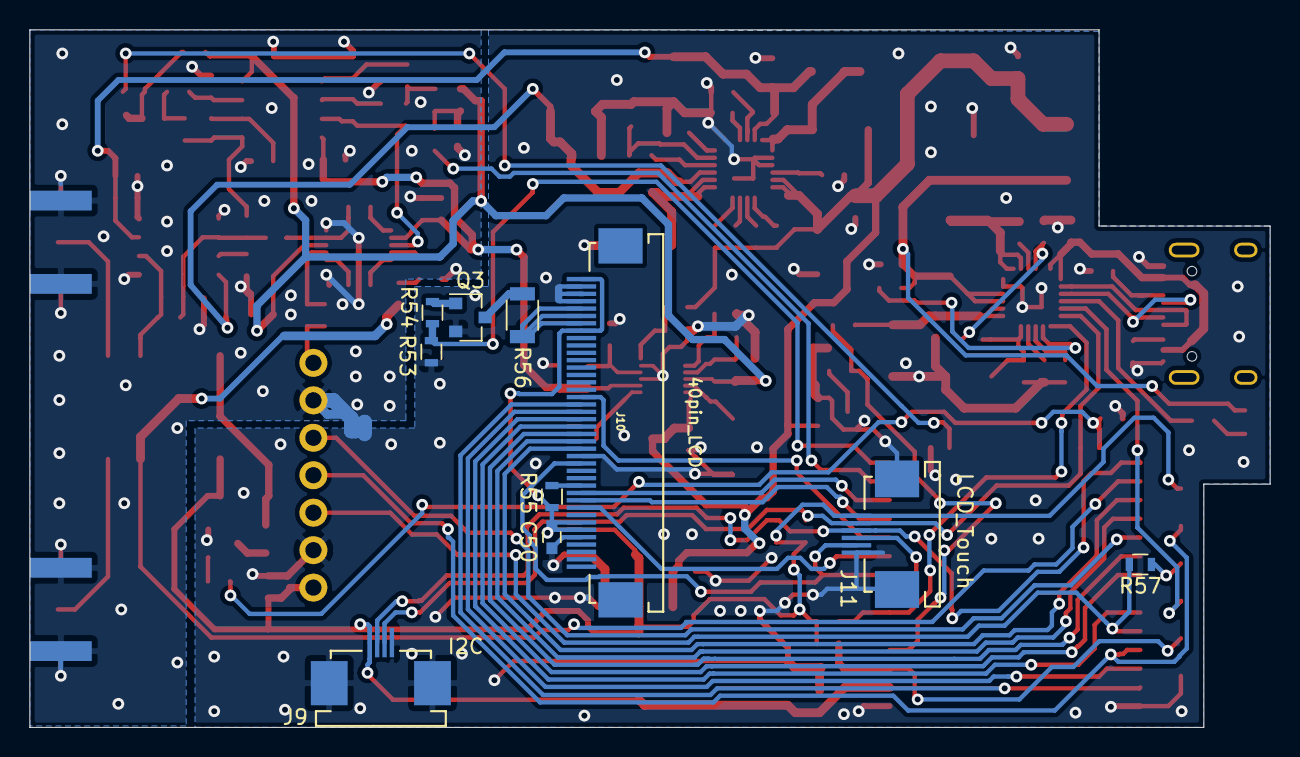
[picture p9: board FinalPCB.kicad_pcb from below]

Board: 2 copper layers, 84.1 x 47.3 mm, 143 parts (10 on the bottom side), 99 nets.

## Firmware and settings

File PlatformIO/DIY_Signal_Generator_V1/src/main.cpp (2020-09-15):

/************************************************************************************
 * 
 * This is an example code used to test R61529 based LCD with FT6236 touch controller
 * connected to an ESP32 MCU through parallel(8080) interface. This code uses eSPI 
 * library
 * 
 * 
 * Note: Although you will find some files that contains R61581 in it, but be aware 
 * that those are modified files from original eSPI library to support R61529 ICs
 * (Some or all code was changed in those header files).
 * 
 * LCD Connection to the ESP32:
 * 
 * D0 -> GPIO 16
 * D1 -> GPIO 17
 * D2 -> GPIO 18
 * D3 -> GPIO 19
 * D4 -> GPIO 21
 * D5 -> GPIO 22
 * D6 -> GPIO 23
 * D7 -> GPIO 25
 * 
 * CSX -> GPIO 33
 * DCX -> GPIO 26
 * RSX -> GPIO 32
 * WRX -> GPIO 27
 * 
 * TOUCH IC connection to the ESP32:
 * 
 * SDA -> GPIO 15
 * SCL -> GPIO 14->0
 * INT -> GPIO 35
 * RST -> GPIO 32 (connected together with the LCD reset pin) 
 *
 *************************************************************************************/


#include <Arduino.h>

#include "../lib/TFT_eSPI/TFT_eSPI.h"
#include "Wire.h"

#include <WiFi.h>
#include <WiFiUdp.h>
#include <ArduinoOTA.h>
#include "ota.h"
#include <EEPROM.h>
#include <WiFiClient.h>
#include <WebServer.h>
#include <HTTPClient.h>

#include <SPI.h>

#include "../lib/AD9833/ad9833.h"
#include "bq24295.h"
#include "../lib/lvgl/src/lvgl.h"

#include "../lib/lcd_interface/lcd_interface.h"
#include "../lib/touch_drv/touch_drv.h"
#include "../lib/generator/generator.h"
#include "../lib/device/device.h"


uint64_t battMeasureTimer = 0;
int battUpdateTimer = 0;


void setup()
{
  
  Device.LoadSettings();
  
  if(Device.IsApOn() || Device.IsWiFiOn()){
    OtaSetup();
  }

  BQ24295_IC charger(15, 0, 100000);

  charger.setI2cWatchdogTimer(0);
  charger.setFastChargeCurrent(0b010000);
  charger.setPreChargeCurrent(0b0001);
  charger.setFastChargeTimer(0);
  charger.setBoostVoltage(0b1000);
  charger.enableOTG(false);

  
  touchInit();
  Wire.beginTransmission(0x38);
  Wire.write(0xA4);
  Wire.write(0x00); //turn on interrupt
  Wire.endTransmission();

  
  interface_init(); //initialise lcd interface: eSPI and lvgl
  
  Device.MeasureBattery();
  interface_update_battery();

}

void loop()
{
  
  OtaHandleRequests();

  Device.ServerHandlesClient();
  lv_task_handler(); /* let the GUI do its work */
 
  delay(1);
  battMeasureTimer++;
  if(battMeasureTimer > 1000){
    battMeasureTimer = 0;
    Device.MeasureBattery();
    if(battUpdateTimer > 5){
      battUpdateTimer = 0;
      interface_update_battery();
    }
    else {
      battUpdateTimer++;
    }
  }
}
